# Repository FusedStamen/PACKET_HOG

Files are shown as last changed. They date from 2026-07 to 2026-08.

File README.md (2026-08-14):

# PACKET_HOG

10-node ESP32-C5 scanner carrier board. One master, a bank of scan nodes, single USB-C power in.

Status: **AVAILABLE** - PacketHog-V1 is tested, assembled, and shipping. First batch of 8 for sale now. PacketHog-V2 (smaller, U.FL-based) is still in development and not yet for sale.

## What it is

Packet Hog C5 is a carrier board built around the Seeed XIAO ESP32-C5. One master node coordinates a bank of scanner nodes over ESP-NOW, each scanning dual-band Wi-Fi (2.4/5 GHz) and BLE. The whole array runs off a single USB-C input.

Built deliberately barebones with power distribution, node bank, antenna breakout, nothing else.

## Buy it

PacketHog-V1, fully assembled: **$100**, first batch of 8, shipping to the US only right now.

[fusedstamen.com/packethogv1](https://fusedstamen.com/packethogv1)

Modules (Seeed XIAO ESP32-C5) and antennas not included. Outside the US, message me on Discord and we'll figure it out.

**Note on the SMA connectors (J1-J10):** they're mounted to the board for physical support only - there's no PCB trace routing antenna signal to them. Each node module's signal reaches its SMA connector through a short U.FL-to-SMA pigtail from the module itself, not through the board's copper. Same setup as the Piglet, in case that's caused confusion before.

**Mounting orientation:** every header position follows the same rule. Seat each XIAO module so its USB-C port faces the same side as the nearby capacitor (e.g. C11 sits next to the H1A/H1B pair) - that side matches the direction the onboard USB-C (J11) faces. The module's U.FL antenna pad ends up on the opposite side. Get this backwards and the module won't seat or power on correctly; double check before powering on.

## Version history

- **Prototype 1** - First routed prototype. Had a wiring mistake around the CH224K USB-C PD negotiation chip: on a "smart" PD-negotiating charger, the board could get handed the wrong voltage, which risked damaging the nodes. Safe with plain 5V "dumb" chargers only.
- **Prototype 2** - CH224K removed entirely; replaced with 5.1kΩ pull-down resistors on CC1/CC2, forcing 5V-default behavior regardless of charger. Also added reverse-polarity protection, a fuse at the power input, bulk + per-node decoupling capacitors, and 10 edge-mounted SMA connectors for external antennas. Had a layout flaw: SMA connector mounts sat too close to the header pins, leaving insufficient clearance to hand-solder/route pigtail connections without crowding the header footprints. Also shipped without mounting holes, so boards couldn't be securely fastened into a case.
- **PacketHog-V1** - Current shipping revision. Fixes clearance flaw by widening the board (77.1mm → 121.1mm) to give proper spacing between the SMA connectors and the header rows. Added M3 mounting holes. Rounded board corners. SMA connectors remain hand-soldered (not PCBA-populated). Small batch (10 boards) ordered and built; tested and now shipping - see [Buy it](#buy-it) above.
- **PacketHog-V2** - Next planned revision. Reduce board size by adding on board (PCBA-populated) SMA connections utilizing U.FL jumper connections.
  
## Status of what's tested

| Component | Status |
|---|---|
| Power distribution | Tested |
| Fully populated board scanning | Tested |
| PacketHog-V1 board fab/assembly | Tested |
| Antenna path (module -> U.FL/SMA pigtail) | Tested |

## License

Licensed under **CC BY-NC 4.0** - see [LICENSE](./LICENSE) for full terms.

Short version: you're free to build one for yourself and modify it for personal, non-commercial use. Selling anything built from this design - boards, kits, or products - requires explicit permission from me first. See the LICENSE file for exactly what that means.

## Contact

- Discord: `Fusedstamen`
- GitHub: [github.com/FusedStamen](https://github.com/FusedStamen)

If you want to use this commercially, reach out through one of the above. Don't assume permission - wait for a yes.

## Name

"Packet Hog" - a reference to [Bilmuri](https://bilmuri.com), not a fork or rename of anyone else's project.

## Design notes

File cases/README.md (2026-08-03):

# StamenScan Case Hardware Guide

This document lists the fasteners and hardware needed to assemble the 3D-printed
cases for the StamenScan V5 and V6 carrier boards. Standoffs and mounting bosses
are printed as part of the case; everything below is hardware you need to source
separately.

---

## V1 Case (board-mounted SMA version)

The V1 case mounts the **lid straight through the board** into the same
standoffs that hold the board down — one screw per corner does both jobs.
The board itself has no independent fastener; it's held in place by the SMA
connector friction fit plus the tight (0.2mm) case-to-board clearance.

| Item | Spec | Qty | Notes |
|---|---|---|---|
| Standoff insert | M3 × D5 × L4 heat-set insert | 4 | Presses into the 4 printed standoff bosses (9mm OD boss, sized for this insert) |
| Combined mounting screw | M3, ~25mm length | 4 | Passes through lid → through board → into the standoff insert |

**Case details:**
- Wall thickness: 2mm
- PCB-to-wall clearance: 0.2mm (tight fit, benchmarked against a reference design)
- 10 SMA ports (5 per side) with a shallow 1mm filleted relief around each hole for connector/nut clearance
- USB-C cutout: 7mm × 14mm
- Lid includes 10 small tab plugs that seat into the open tops of the SMA slots when closed

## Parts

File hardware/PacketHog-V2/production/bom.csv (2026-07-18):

Designator | Footprint | Quantity | Value | LCSC Part #
C1, C4 | CP_Elec_6.3x5.4 | 2 | CP_Elec_6.3x5.4
C10, C11, C12, C13, C14, C15, C6, C7, C8, C9 | 0603 | 10 | 10uF
C16, C17, C18, C2, C3, C5 | 0603 | 6 | 1uF
D1 | D_SMB | 1 | D_SMB
F1 | 1206 | 1 | Fuse_1206_3216Metric
FAN1 | PinHeader_1x02_P2.54mm_Vertical | 1 | PinHeader_1x02_P2.54mm_Vertical
H10A, H10B, H1A, H1B, H2A, H2B, H3A, H3B, H4A, H4B, H5A, H5B, H6A, H6B, H7A, H7B, H8A, H8B, H9A, H9B | PinSocket_1x07_P2.54mm_Vertical | 20 | PinSocket_1x07_P2.54mm_Vertical
J1, J10, J2, J3, J4, J5, J6, J7, J8, J9 | SMA_BAT_Wireless_BWSMA-KWE-Z001 | 10 | SMA_BAT_Wireless_BWSMA-KWE-Z001
J11 | USB_C_Receptacle_GCT_USB4105-xx-A_16P_TopMnt_Horizontal | 1 | USB_C_Receptacle_GCT_USB4105
K1, K10, K2, K3, K4, K5, K6, K7, K8, K9 | U.FL_Hirose_U.FL-R-SMT-1_Vertical | 10 | U.FL_Hirose_U.FL-R-SMT-1_Vertical
R1, R2 | 0603 | 2 | 5.1k

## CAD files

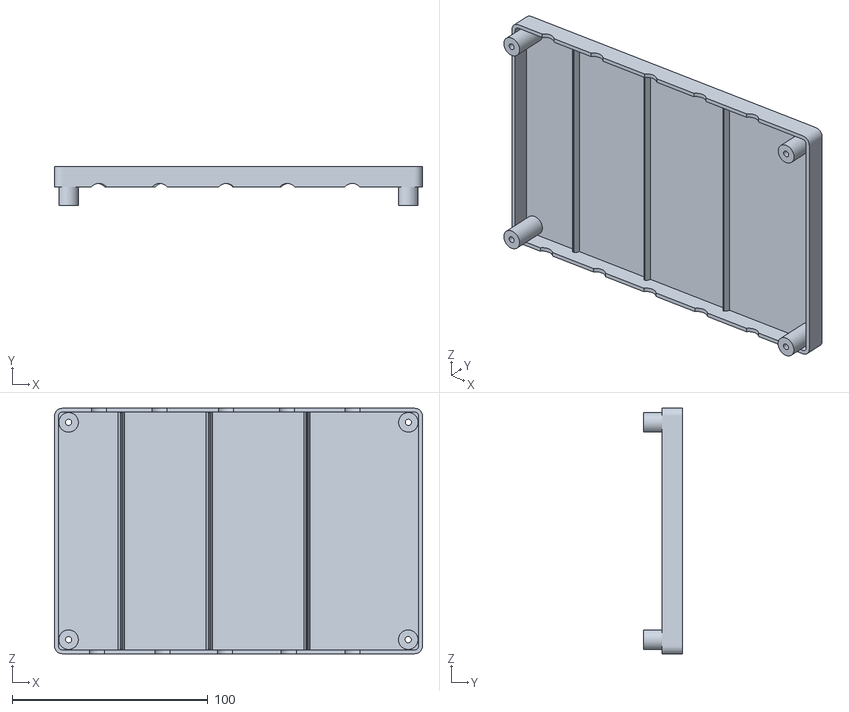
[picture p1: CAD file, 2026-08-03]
cases/Packet_Hog-V1 Case/Packet_Hog-V1-Lid-V3.stl
188.1 x 20.0 x 125.5

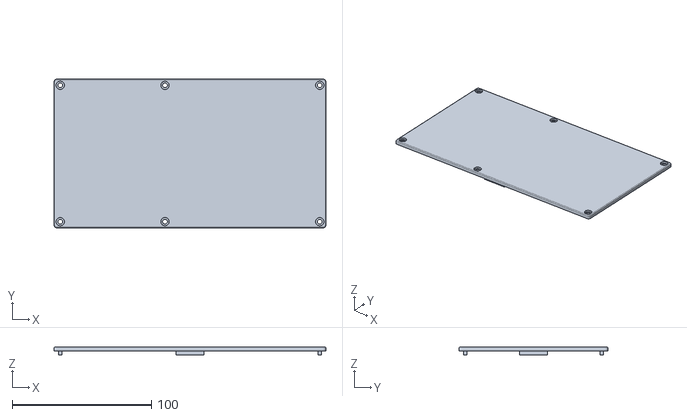
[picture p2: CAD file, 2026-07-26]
cases/Prototype Case/Prototype_Case_Lid_V2.stl
195.6 x 107.0 x 6.00

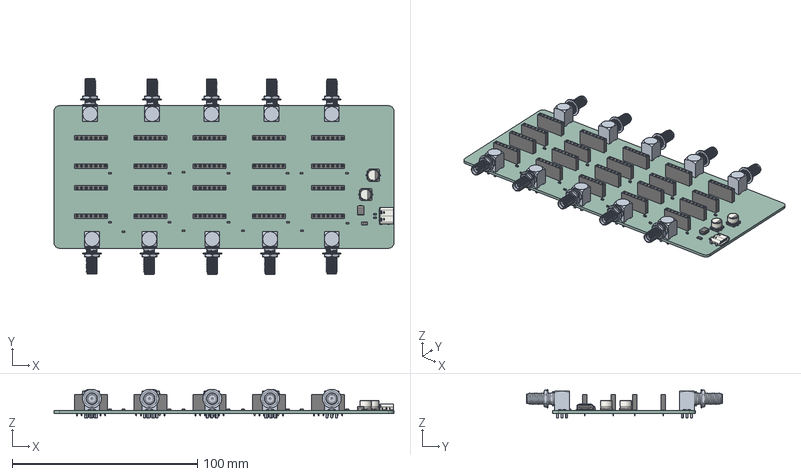
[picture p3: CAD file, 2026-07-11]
hardware/PacketHog-V2/PacketHog-V2.step
183.6 x 105.6 x 15.4 mm
C_0603_1608Metric x 16
SMA6252A9-002-3GT50G-_SW0001 x 10
PinSocket_1x07_P2.54mm_Vertical x 20
R_0603_1608Metric x 2
Fuse_1206_3216Metric
USB_C_Receptacle_16P_TopMnt_Horizontal_GCT_USB4105-xx-A
CP_Elec_63x54 x 2
D_SMB
ESP32-C5-Board-V5-SMA_PCB

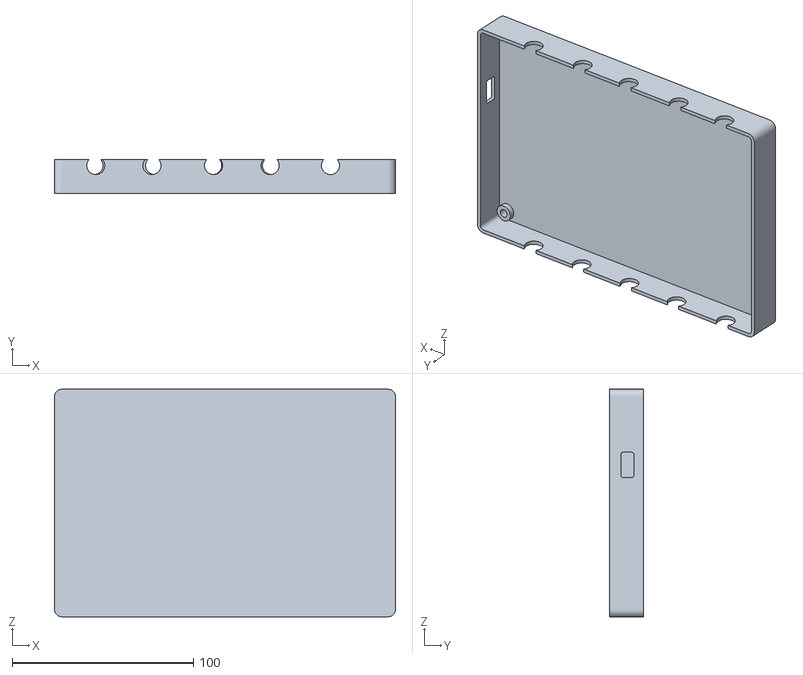
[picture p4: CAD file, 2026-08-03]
cases/Packet_Hog-V1 Case/Packet_Hog-V1-Tray-V3.stl
188.1 x 18.5 x 125.5

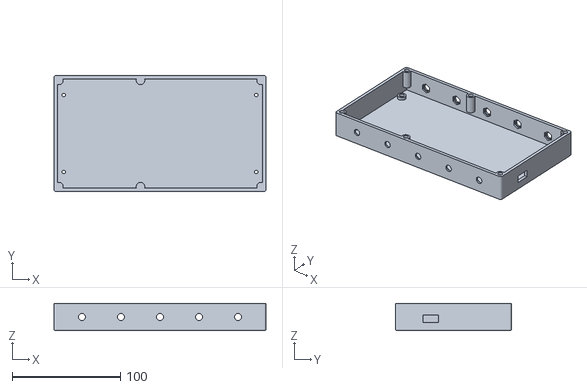
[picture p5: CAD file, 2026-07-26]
cases/Prototype Case/Prototype_Case_Tray_V2.stl
195.6 x 107.0 x 25.0

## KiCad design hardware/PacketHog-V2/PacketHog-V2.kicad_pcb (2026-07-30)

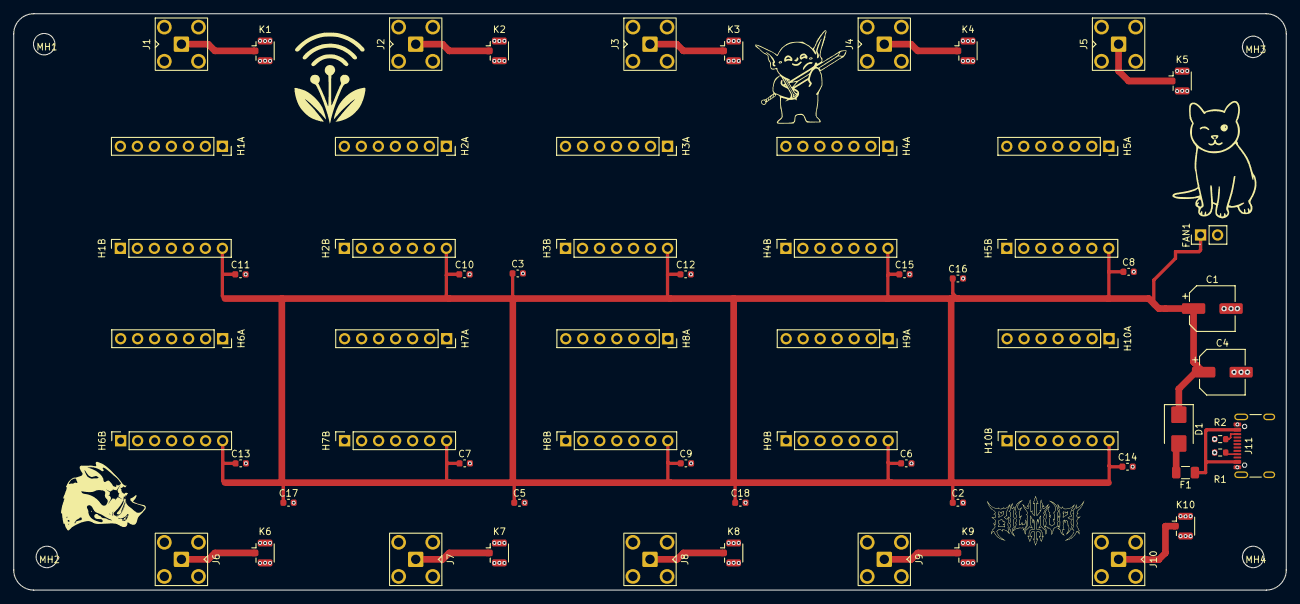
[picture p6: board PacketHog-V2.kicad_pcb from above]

Board: 2 copper layers, 190.1 x 86.1 mm, 68 parts (0 on the bottom side), 16 nets.

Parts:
C1, C4: CP_Elec_6.3x5.4
C2, C3, C5, C16, C17, C18: 1uF; C_0603_1608Metric
C6, C7, C8, C9, C10, C11, C12, C13, C14, C15: 10uF; C_0603_1608Metric
D1: D_SMB
F1: Fuse_1206_3216Metric
FAN1: PinHeader_1x02_P2.54mm_Vertical
H1A, H1B, H2A, H2B, H3A, H3B, H4A, H4B, H5A, H5B, H6A, H6B, H7A, H7B, H8A, H8B, H9A, H9B, H10A, H10B: PinSocket_1x07_P2.54mm_Vertical
J1, J2, J3, J4, J5, J6, J7, J8, J9, J10: SMA_BAT_Wireless_BWSMA-KWE-Z001
J11: USB_C_Receptacle_GCT_USB4105; USB_C_Receptacle_GCT_USB4105-xx-A_16P_TopMnt_Horizontal
K1, K2, K3, K4, K5, K6, K7, K8, K9, K10: U.FL_Hirose_U.FL-R-SMT-1_Vertical
MH1, MH2, MH3, MH4: MountingHole_3.2mm_M3
R1, R2: 5.1k; R_0603_1608Metric

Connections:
+5V: C1.1, C2.1, C3.1, C4.1, C5.1, C6.1, C7.1, C8.1, C9.1, C10.1, C11.1, C12.1, C13.1, C14.1, C15.1, C16.1, C17.1, C18.1, D1.1, FAN1.1, H1B.7, H2B.7, H3B.7, H4B.7, H5B.7, H6B.7, H7B.7, H8B.7, H9B.7, H10B.7
CC1: J11.B5, R2.2
CC2: J11.A5, R1.2
F1_OUT: D1.2, F1.2
GND: C1.2, C2.2, C3.2, C4.2, C5.2, C6.2, C7.2, C8.2, C9.2, C10.2, C11.2, C12.2, C13.2, C14.2, C15.2, C16.2, C17.2, C18.2, FAN1.2, H1B.6, H2B.6, H3B.6, H4B.6, H5B.6, H6B.6, H7B.6, H8B.6, H9B.6, H10B.6, J1.2, J2.2, J3.2, J4.2, J5.2, J6.2, J7.2, J8.2, J9.2, J10.2, J11.A1, J11.A12, J11.B1, J11.B12, J11.SH, K1.2, K2.2, K3.2, K4.2, K5.2, K6.2, K7.2, K8.2, K9.2, K10.2, R1.1, R2.1
SMA1: J1.1, K1.1
SMA2: J2.1, K2.1
SMA3: J3.1, K3.1
SMA4: J4.1, K4.1
SMA5: J5.1, K5.1
SMA6: J6.1, K6.1
SMA7: J7.1, K7.1
SMA8: J8.1, K8.1
SMA9: J9.1, K9.1
SMA10: J10.1, K10.1
VBUS: F1.1, J11.A4, J11.A9, J11.B4, J11.B9

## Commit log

2026-11-08 Add files via upload
    adding v2 case files
2026-11-09 Update README.md
    added board size
